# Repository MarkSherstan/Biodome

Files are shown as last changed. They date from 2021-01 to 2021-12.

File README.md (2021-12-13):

# Biodome
Hardware, firmware, and Bluetooth Low Energy (BLE) iOS app for monitoring plants around the house. Inspired by the Cloud Forest in Singapore.

<p align="center">
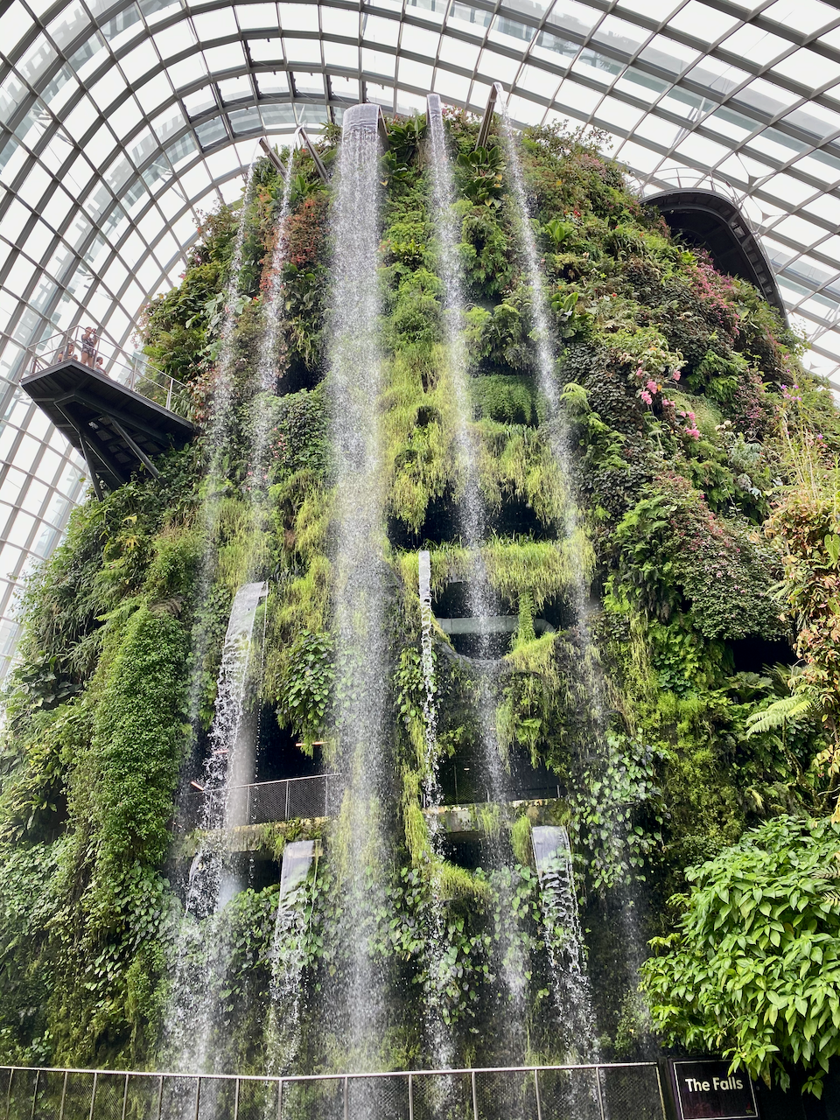
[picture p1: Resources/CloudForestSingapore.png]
  
</p>

# Requirements
## App
* Computer running macOS
* Xcode 13.0 or greater
* Device running iOS 15.0 or greater (UI built for iPhone Xs)

## Hardware
* Raspberry Pi 3B+
* Custom PCB board (boards are built with KiCad 5 and manufactured by JLCPCB))

## Firmware
* Python 3 
* Standard Raspbian OS

# Setup
## App
* Build using Xcode and upload to iOS device. See `/Resources` for example screenshots of the app using simulated data.

## Hardware
* Power on system (remember RPi is 3V3 logic)

## Firmware
As of BlueZ version 5.43 (currently shipped with Raspbian), some BLE aspects are still experimental. You will need to add the 'Experimental' flag to the bluetooth daemon. Open the file: `sudo nano /etc/systemd/system/dbus-org.bluez.service` and add the `-E` flag at the end of the `ExecStart` line. It should look like this:
```
ExecStart=/usr/lib/bluetooth/bluetoothd -E
```
To disable auto battery reading and prevent connection issues, edit the same file and add `-P battery` to the end of the `ExecStart` line to disable the Battery feature in bluetooth. Your ExecStart should look something like:
```
ExecStart=/usr/lib/bluetooth/bluetoothd -E -P battery
```
Run `systemctl daemon-reload` and `systemctl restart bluetooth` to apply the changes to the Bluetooth service

Navigate to `\Firmware` and run `python3 main.py`. The RPi is now ready to share values with the iOS app.

# Future Work
## App
* Fix connection logic
* Connect to multiple devices
* More general UI layout

### Resources 
Core Bluetooth
* https://www.raywenderlich.com/231-core-bluetooth-tutorial-for-ios-heart-rate-monitor#toc-anchor-009
* https://www.novelbits.io/intro-ble-mobile-development-ios-part-2/
* https://learn.adafruit.com/build-a-bluetooth-app-using-swift-5/code
* https://punchthrough.com/core-bluetooth-basics/

Style and UI:
*  https://betterprogramming.pub/flat-design-list-swiftui-part-i-ab9e841720cd
*  https://developer.apple.com/tutorials/swiftui/building-lists-and-navigation
*  https://betterprogramming.pub/creating-an-apple-like-splash-screen-in-swiftui-fdeb36b47e81

Other:
* https://www.raywenderlich.com/2164-arduino-tutorial-integrating-bluetooth-le-and-ios-with-swift#toc-anchor-009

## Hardware
* Use digital pin to wake up moisture sensor (change to 3.3V 555 timer)
* Check backorder on BME280 - Not currently used for V1
* Make the board act as a shield for the Pi (pins and mounting holes)

## Firmware 
* Website JavaScript interface (similar to Octo-Print)
* Slow logging... Log on ram for 24h then save to SD card (Dont burn out SD card)
* Photos/Image Processing, moisture, humidity, temperature, light, pressure

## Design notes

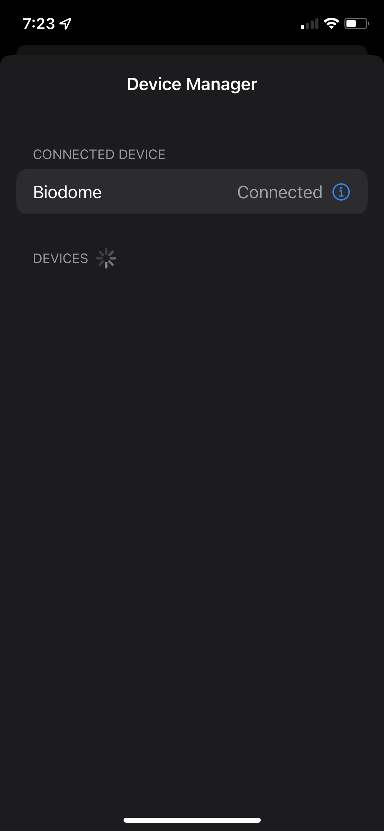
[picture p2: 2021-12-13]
Resources/AppDeviceManager.PNG

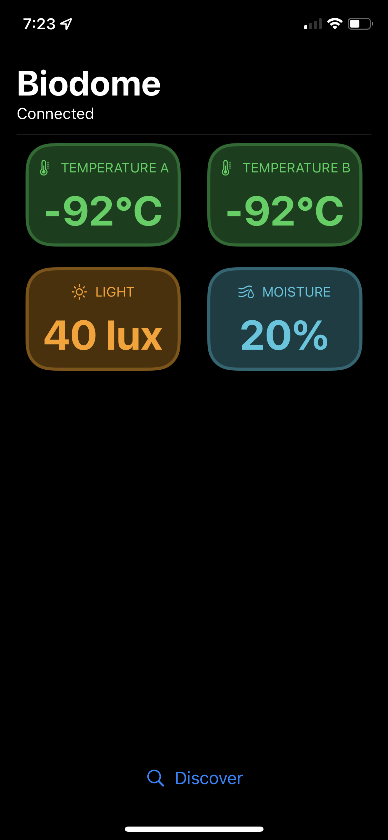
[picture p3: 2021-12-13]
Resources/AppMainView.PNG

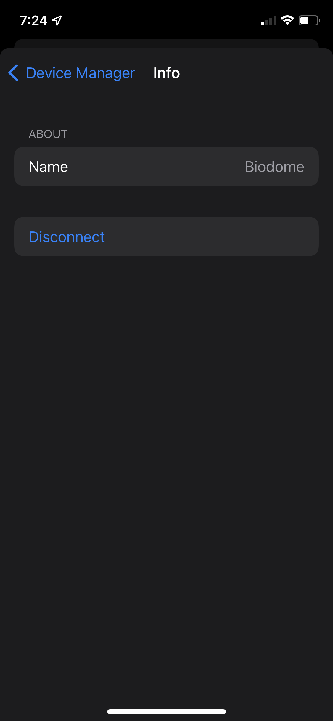
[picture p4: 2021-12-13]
Resources/AppInfoView.PNG

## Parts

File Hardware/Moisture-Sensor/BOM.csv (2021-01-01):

Reference | Quantity | Value | Footprint | Digi-Key # | Digi-Key Link | Manufacturer | Manufacturer #
C1 | 1 | 470 pF | Capacitor_SMD:C_0603_1608Metric_Pad1.05x0.95mm_HandSolder
C2 C3 | 2 | 0.1 uF | Capacitor_SMD:C_0603_1608Metric_Pad1.05x0.95mm_HandSolder
C4 | 1 | 10 nF | Capacitor_SMD:C_0603_1608Metric_Pad1.05x0.95mm_HandSolder
C5 | 1 | 4.7 uF | Capacitor_SMD:C_0603_1608Metric_Pad1.05x0.95mm_HandSolder
D1 | 1 | Green 2.2V 20mA | LED_SMD:LED_0603_1608Metric_Pad1.05x0.95mm_HandSolder
D2 | 1 | 4148 | Diode_SMD:D_SOD-123 | SMMSD4148T3GOSCT-ND | https://www.digikey.ca/en/products/detail/on-semiconductor/SMMSD4148T3G/3062785 | ON Semiconductor | SMMSD4148T3G
H1 H2 | 2 | M2 | MountingHole:MountingHole_2.2mm_M2_ISO14580_Pad
J1 | 1 | Input | Connector_PinHeader_2.54mm:PinHeader_1x03_P2.54mm_Vertical
R1 | 1 | 150 ohm | Resistor_SMD:R_0603_1608Metric_Pad1.05x0.95mm_HandSolder
R2 | 1 | DNP | Resistor_SMD:R_0603_1608Metric_Pad1.05x0.95mm_HandSolder
R3 | 1 | 0 ohm | Resistor_SMD:R_0603_1608Metric_Pad1.05x0.95mm_HandSolder
R4 | 1 | 1.5 kohm | Resistor_SMD:R_0603_1608Metric_Pad1.05x0.95mm_HandSolder
R5 | 1 | 2.4 kohm | Resistor_SMD:R_0603_1608Metric_Pad1.05x0.95mm_HandSolder
R6 | 1 | 100 ohm | Resistor_SMD:R_0603_1608Metric_Pad1.05x0.95mm_HandSolder
R7 | 1 | 10 kohm | Resistor_SMD:R_0603_1608Metric_Pad1.05x0.95mm_HandSolder
R8 | 1 | 1 Mohm | Resistor_SMD:R_0603_1608Metric_Pad1.05x0.95mm_HandSolder
U1 | 1 | LMV358 | Package_SO:SOIC-8_3.9x4.9mm_P1.27mm | 296-39049-5-ND | https://www.digikey.ca/en/products/detail/texas-instruments/LMV358ID/1510583 | Texas Instruments | LMV358ID
U2 | 1 | NE555 | Package_SO:SOIC-8_3.9x4.9mm_P1.27mm | 296-6501-1-ND | https://www.digikey.ca/en/products/detail/texas-instruments/NE555DR/372491 | Texas Instruments | NE555DR

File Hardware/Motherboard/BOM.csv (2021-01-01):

Reference | Quantity | Value | Footprint | Digi-Key # | Digi-Key Link | Manufacturer | Manufacturer #
C1 C5 | 2 | 1 uF | Capacitor_SMD:C_0603_1608Metric_Pad1.05x0.95mm_HandSolder
C3 C2 C4 | 3 | 0.1 uF | Capacitor_SMD:C_0603_1608Metric_Pad1.05x0.95mm_HandSolder
D1 | 1 | Blue 3.3V 20mA | LED_SMD:LED_0603_1608Metric_Pad1.05x0.95mm_HandSolder
D2 | 1 | Green 2.2V 20mA | LED_SMD:LED_0603_1608Metric_Pad1.05x0.95mm_HandSolder
H1 H2 H3 H4 | 4 | M3 | MountingHole:MountingHole_3.2mm_M3_ISO7380_Pad
J1 | 1 | AUX Analog A | Connector_PinHeader_2.54mm:PinHeader_1x03_P2.54mm_Vertical
J10 | 1 | Moisture 4 | Connector_PinHeader_2.54mm:PinHeader_1x03_P2.54mm_Vertical
J11 | 1 | Moisture 5 | Connector_PinHeader_2.54mm:PinHeader_1x03_P2.54mm_Vertical
J12 | 1 | Power In | Connector_BarrelJack:BarrelJack_CUI_PJ-102AH_Horizontal | CP-102AH-ND | https://www.digikey.ca/en/products/detail/cui-devices/PJ-102AH/408448?s=N4IgTCBcDaIAoCkC0BGADGAggCRAXQF8g | CUI Devices | PJ-102AH
J2 | 1 | AUX Analog B | Connector_PinHeader_2.54mm:PinHeader_1x03_P2.54mm_Vertical
J3 | 1 | RPi 3B+ | Connector_PinHeader_2.54mm:PinHeader_2x20_P2.54mm_Vertical
J4 | 1 | AUX Digital A | Connector_PinHeader_2.54mm:PinHeader_1x03_P2.54mm_Vertical
J5 | 1 | AUX Digital B | Connector_PinHeader_2.54mm:PinHeader_1x03_P2.54mm_Vertical
J6 | 1 | Moisture 0 | Connector_PinHeader_2.54mm:PinHeader_1x03_P2.54mm_Vertical
J7 | 1 | Moisture 1 | Connector_PinHeader_2.54mm:PinHeader_1x03_P2.54mm_Vertical
J8 | 1 | Moisture 2 | Connector_PinHeader_2.54mm:PinHeader_1x03_P2.54mm_Vertical
J9 | 1 | Moisture 3 | Connector_PinHeader_2.54mm:PinHeader_1x03_P2.54mm_Vertical
R18 | 1 | 150 ohm | Resistor_SMD:R_0603_1608Metric_Pad1.05x0.95mm_HandSolder
R2 R4 R8 R10 R12 R14 | 6 | 1.7 kohm | Resistor_SMD:R_0603_1608Metric_Pad1.05x0.95mm_HandSolder
R3 R5 R9 R11 R13 R15 | 6 | 3.3 kohm | Resistor_SMD:R_0603_1608Metric_Pad1.05x0.95mm_HandSolder
R6 R7 R16 R17 | 4 | 4.7 kohm | Resistor_SMD:R_0603_1608Metric_Pad1.05x0.95mm_HandSolder
U1 | 1 | MCP3008 | Package_SO:SOIC-16_3.9x9.9mm_P1.27mm | MCP3008T-I/SLCT-ND | https://www.digikey.ca/en/products/detail/microchip-technology/MCP3008T-I-SL/319424 | Microchip Technology | MCP3008T-I/SL
U2 | 1 | BME280 | Package_LGA:Bosch_LGA-8_2.5x2.5mm_P0.65mm_ClockwisePinNumbering | 828-1063-1-ND | https://www.digikey.ca/en/products/detail/bosch-sensortec/BME280/6136306 | Bosch Sensortec | BME280
U3 | 1 | VEML7700 | Custom:VEML7700 | VEML7700CT-ND | https://www.digikey.ca/en/products/detail/vishay-semiconductor-opto-division/VEML7700-TR/5820243 | Vishay Semiconductor Opto Division | VEML7700-TR

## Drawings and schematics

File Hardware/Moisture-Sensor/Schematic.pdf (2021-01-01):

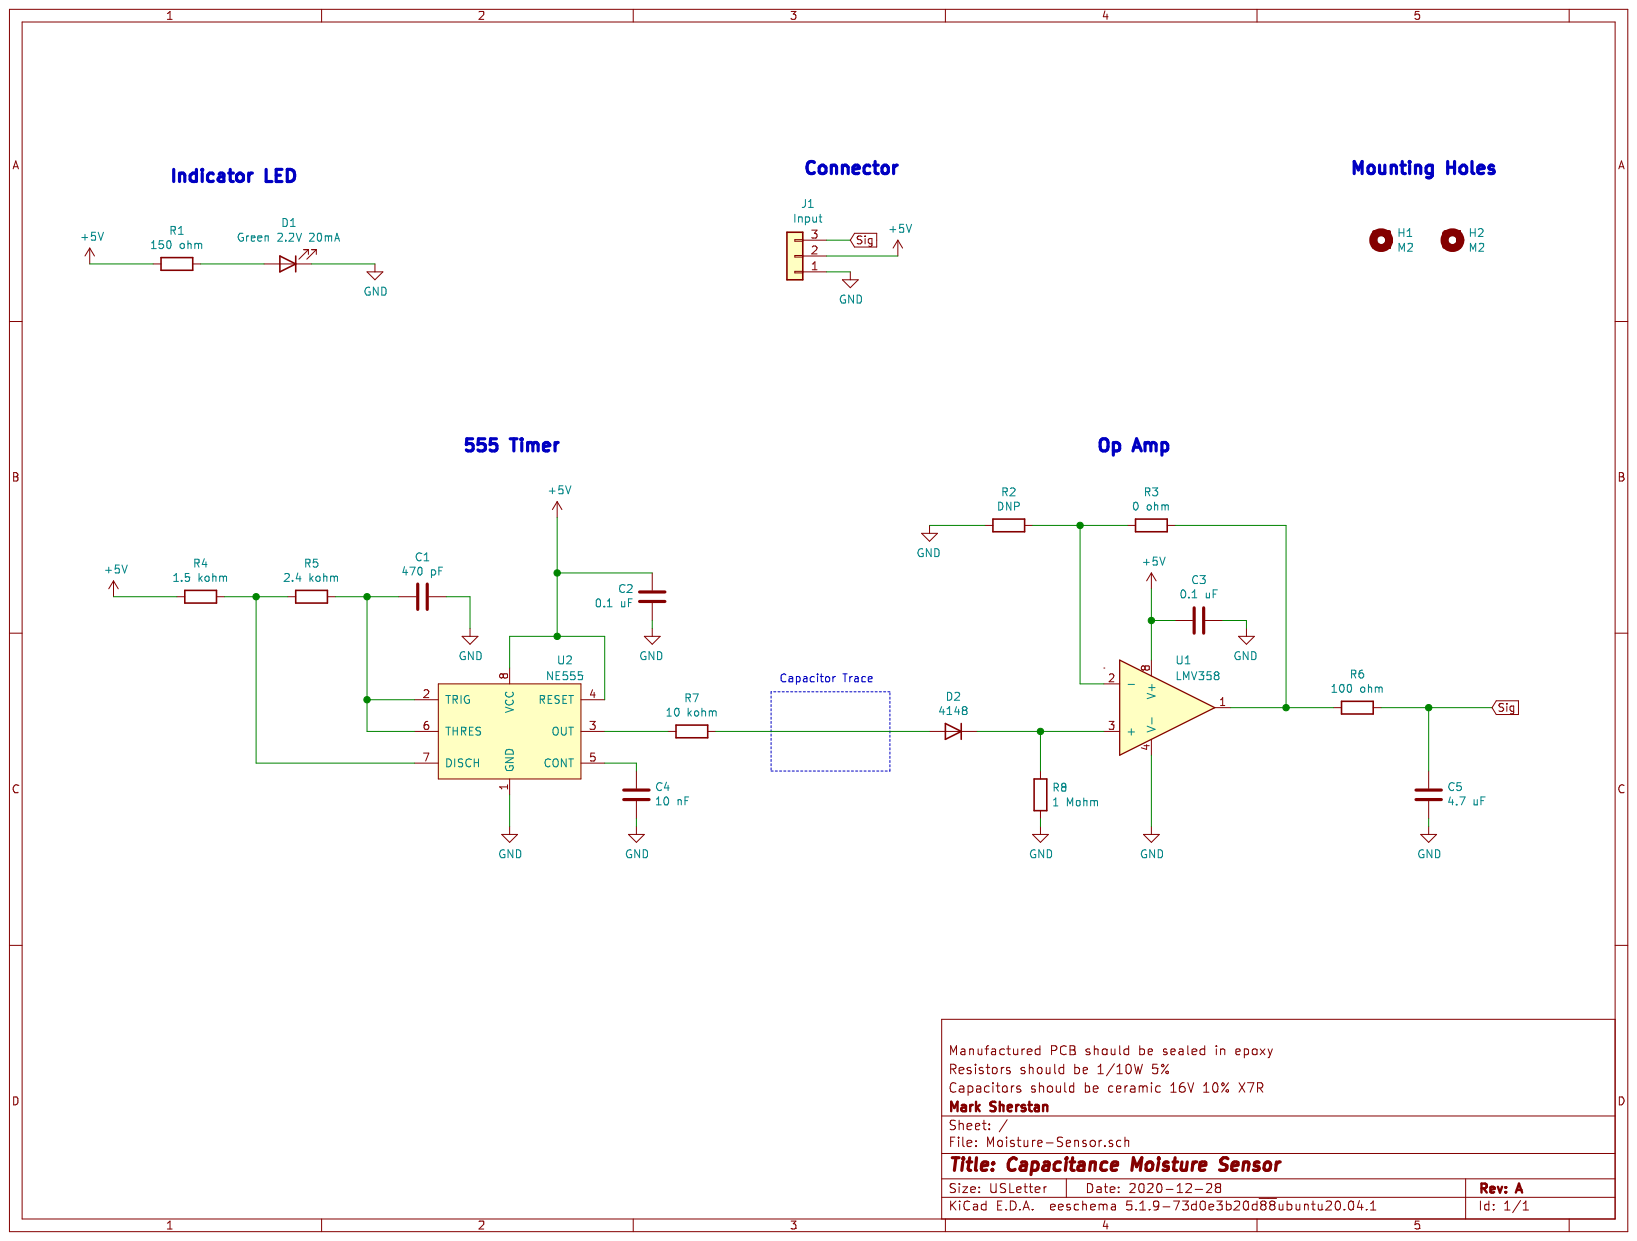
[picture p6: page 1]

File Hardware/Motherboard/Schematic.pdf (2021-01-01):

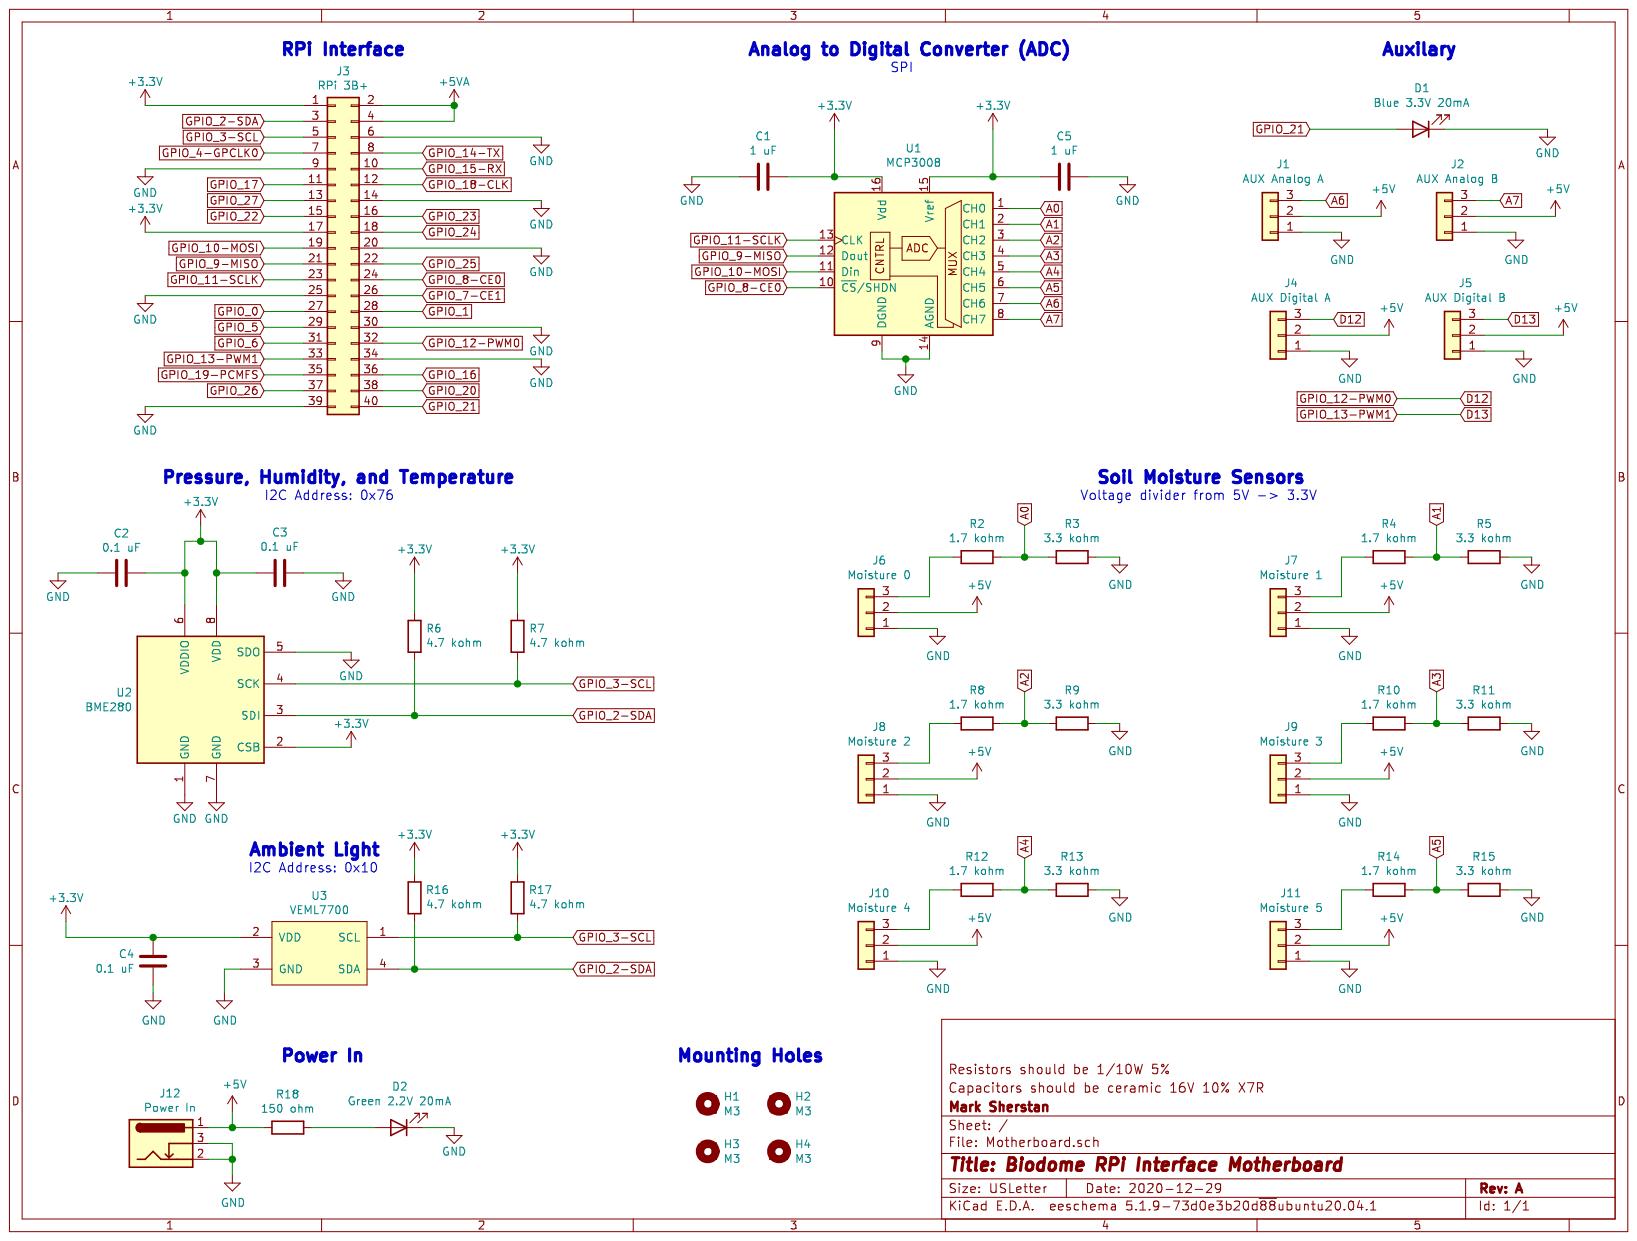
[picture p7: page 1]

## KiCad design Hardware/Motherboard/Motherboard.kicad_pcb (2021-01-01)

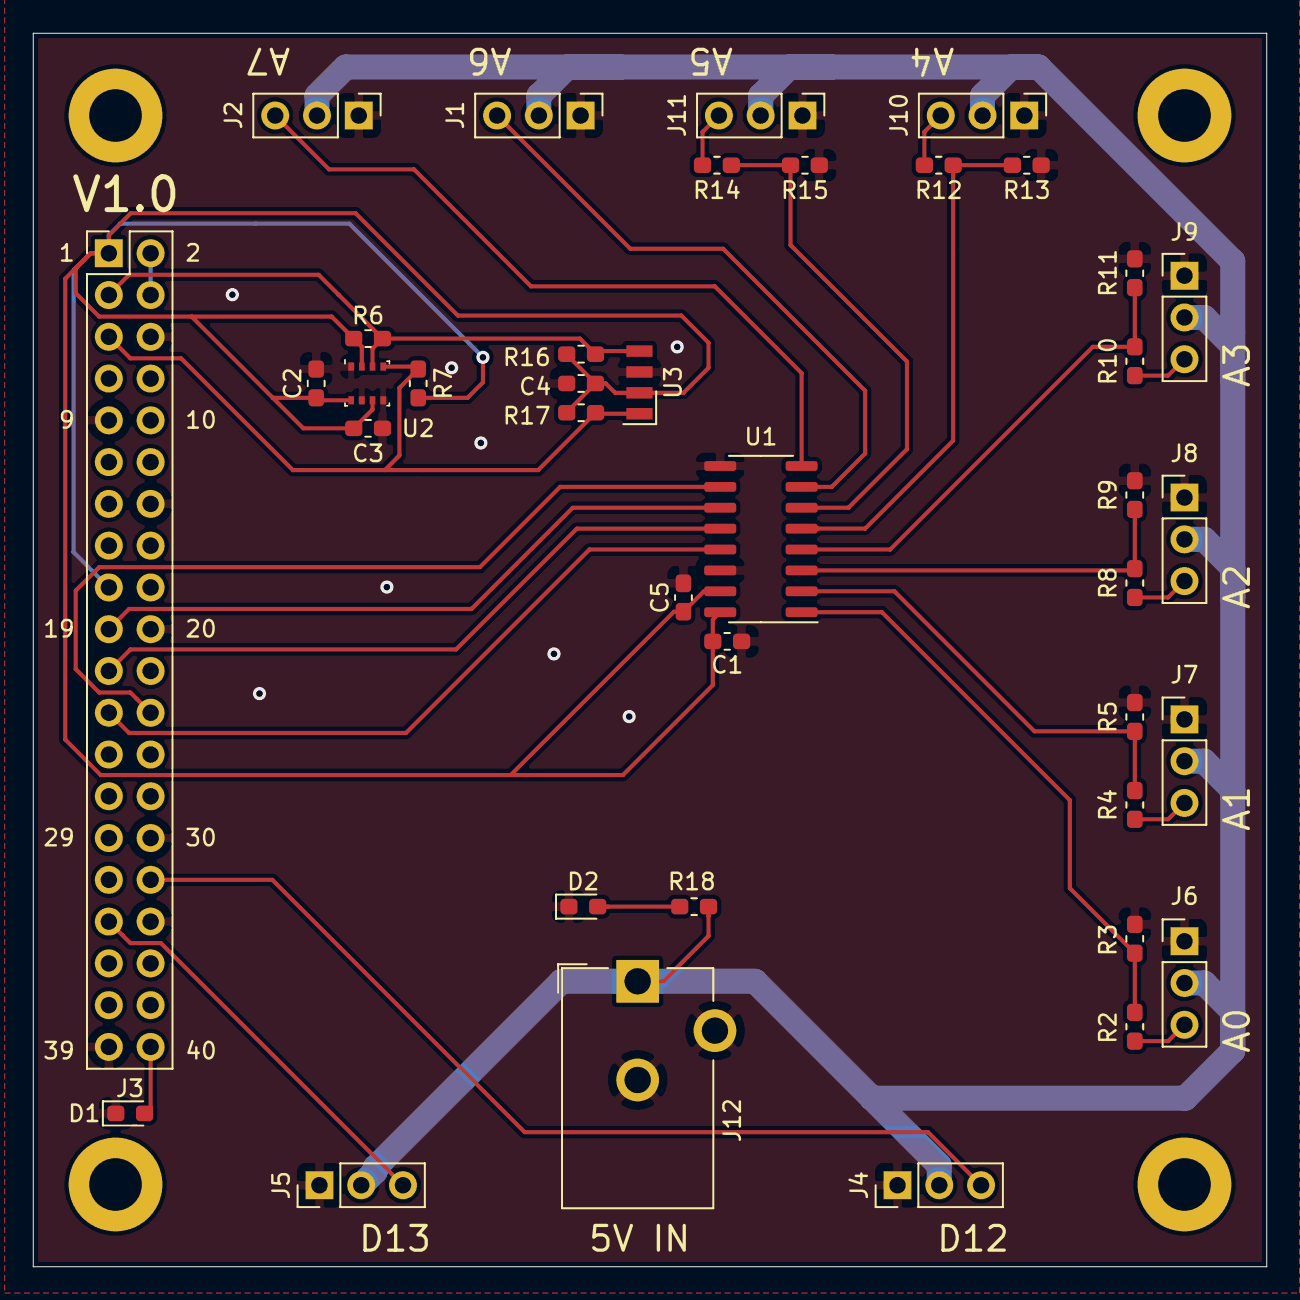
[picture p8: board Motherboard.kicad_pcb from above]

Board: 2 copper layers, 75.0 x 75.0 mm, 43 parts (0 on the bottom side), 28 nets.

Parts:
C1: 1 uF; C_0603_1608Metric_Pad1.05x0.95mm_HandSolder
C2, C3, C4: 0.1 uF; C_0603_1608Metric_Pad1.05x0.95mm_HandSolder
C5: 1 uF; C_0603_1608Metric_Pad1.08x0.95mm_HandSolder
D1: Blue 3.3V 20mA; LED_0603_1608Metric_Pad1.05x0.95mm_HandSolder
D2: Green 2.2V 20mA; LED_0603_1608Metric_Pad1.05x0.95mm_HandSolder
H1, H2, H3, H4: M3; MountingHole_3.2mm_M3_ISO7380_Pad
J1: AUX Analog A; PinHeader_1x03_P2.54mm_Vertical
J2: AUX Analog B; PinHeader_1x03_P2.54mm_Vertical
J3: RPi 3B+; PinHeader_2x20_P2.54mm_Vertical
J4: AUX Digital A; PinHeader_1x03_P2.54mm_Vertical
J5: AUX Digital B; PinHeader_1x03_P2.54mm_Vertical
J6: Moisture 0; PinHeader_1x03_P2.54mm_Vertical
J7: Moisture 1; PinHeader_1x03_P2.54mm_Vertical
J8: Moisture 2; PinHeader_1x03_P2.54mm_Vertical
J9: Moisture 3; PinHeader_1x03_P2.54mm_Vertical
J10: Moisture 4; PinHeader_1x03_P2.54mm_Vertical
J11: Moisture 5; PinHeader_1x03_P2.54mm_Vertical
J12: Power In; BarrelJack_CUI_PJ-102AH_Horizontal
R2, R4, R8, R10, R12, R14: 1.7 kohm; R_0603_1608Metric_Pad1.05x0.95mm_HandSolder
R3, R5, R9, R11, R13, R15: 3.3 kohm; R_0603_1608Metric_Pad1.05x0.95mm_HandSolder
R6, R7, R16, R17: 4.7 kohm; R_0603_1608Metric_Pad1.05x0.95mm_HandSolder
R18: 150 ohm; R_0603_1608Metric_Pad1.05x0.95mm_HandSolder
U1: MCP3008; SOIC-16_3.9x9.9mm_P1.27mm
U2: BME280; Bosch_LGA-8_2.5x2.5mm_P0.65mm_ClockwisePinNumbering
U3: VEML7700

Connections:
+3V3: C1.2, C2.1, C3.1, C4.1, C5.1, J3.1, J3.17, R6.2, R7.2, R16.2, R17.2, U1.15, U1.16, U2.2, U2.6, U2.8, U3.2
+5V: J1.2, J2.2, J4.2, J5.2, J6.2, J7.2, J8.2, J9.2, J10.2, J11.2, J12.1, R18.1
+5VA: J3.2, J3.4
A0: R2.2, R3.1, U1.1
A1: R4.2, R5.1, U1.2
A2: R8.2, R9.1, U1.3
A3: R10.2, R11.1, U1.4
A4: R12.2, R13.1, U1.5
A5: R14.2, R15.1, U1.6
A6: J1.3, U1.7
A7: J2.3, U1.8
D12: J3.32, J4.3
D13: J3.33, J5.3
GND: C1.1, C2.2, C3.2, C4.2, C5.2, D1.1, D2.1, J1.1, J2.1, J3.6, J3.9, J3.14, J3.20, J3.25, J3.30, J3.34, J3.39, J4.1, J5.1, J6.1, J7.1, J8.1, J9.1, J10.1, J11.1, J12.2, J12.3, R3.2, R5.2, R9.2, R11.2, R13.2, R15.2, U1.9, U1.14, U2.1, U2.5, U2.7, U3.3
GPIO_2-SDA: J3.3, R6.1, R16.1, U2.3, U3.4
GPIO_3-SCL: J3.5, R7.1, R17.1, U2.4, U3.1
GPIO_8-CE0: J3.24, U1.10
GPIO_9-MISO: J3.21, U1.12
GPIO_10-MOSI: J3.19, U1.11
GPIO_11-SCLK: J3.23, U1.13
GPIO_21: D1.2, J3.40
unnamed: D2.2, R18.2
unnamed: J6.3, R2.1
unnamed: J7.3, R4.1
unnamed: J8.3, R8.1
unnamed: J9.3, R10.1
unnamed: J10.3, R12.1
unnamed: J11.3, R14.1

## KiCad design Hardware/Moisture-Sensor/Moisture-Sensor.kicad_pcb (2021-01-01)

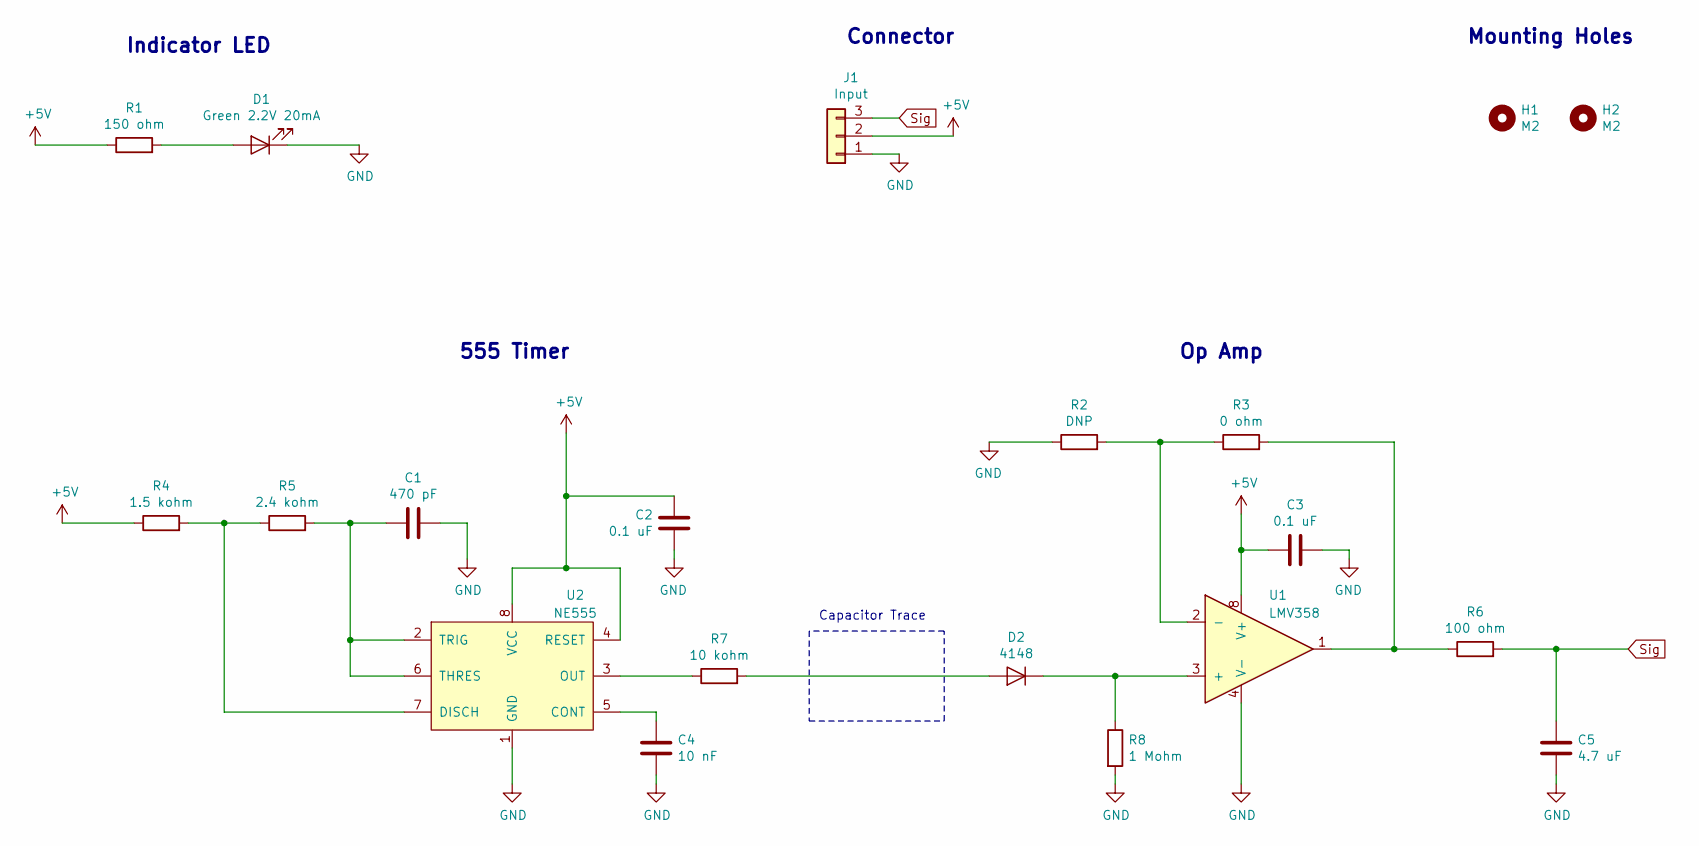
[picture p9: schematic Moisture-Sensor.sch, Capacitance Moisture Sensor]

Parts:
C1: 470 pF; C_0603_1608Metric_Pad1.05x0.95mm_HandSolder
C2, C3: 0.1 uF; C_0603_1608Metric_Pad1.05x0.95mm_HandSolder
C4: 10 nF; C_0603_1608Metric_Pad1.05x0.95mm_HandSolder
C5: 4.7 uF; C_0603_1608Metric_Pad1.05x0.95mm_HandSolder
D1: Green 2.2V 20mA; LED_0603_1608Metric_Pad1.05x0.95mm_HandSolder
D2: 4148; D_SOD-123; Manufacturer # SMMSD4148T3G; Digi-Key # SMMSD4148T3GOSCT-ND
H1, H2: M2; MountingHole_2.2mm_M2_ISO14580_Pad
J1: Input; PinHeader_1x03_P2.54mm_Vertical
R1: 150 ohm; R_0603_1608Metric_Pad1.05x0.95mm_HandSolder
R2: DNP; R_0603_1608Metric_Pad1.05x0.95mm_HandSolder
R3: 0 ohm; R_0603_1608Metric_Pad1.05x0.95mm_HandSolder
R4: 1.5 kohm; R_0603_1608Metric_Pad1.05x0.95mm_HandSolder
R5: 2.4 kohm; R_0603_1608Metric_Pad1.05x0.95mm_HandSolder
R6: 100 ohm; R_0603_1608Metric_Pad1.05x0.95mm_HandSolder
R7: 10 kohm; R_0603_1608Metric_Pad1.05x0.95mm_HandSolder
R8: 1 Mohm; R_0603_1608Metric_Pad1.05x0.95mm_HandSolder
U1: LMV358; SOIC-8_3.9x4.9mm_P1.27mm; Manufacturer # LMV358ID; Digi-Key # 296-39049-5-ND
U2: NE555; SOIC-8_3.9x4.9mm_P1.27mm; Manufacturer # NE555DR; Digi-Key # 296-6501-1-ND

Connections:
+5V: C2.2, C3.2, J1.2, R1.1, R4.1, U1.8 (V+), U2.4 (RESET), U2.8 (VCC)
GND: C1.1, C2.1, C3.1, C4.1, C5.1, D1.1 (K), J1.1, R2.1, R8.2, U1.4 (V-), U2.1 (GND)
unnamed: C1.2, R5.2, U2.2 (TRIG), U2.6 (THRES)
unnamed: C4.2, U2.5 (CONT)
unnamed: D1.2 (A), R1.2
unnamed: D2.1 (K), R8.1, U1.3 (+)
unnamed: D2.2 (A), R7.2
unnamed: R2.2, R3.1, U1.2 (-)
unnamed: R3.2, R6.1, U1.1
unnamed: R4.2, R5.1, U2.7 (DISCH)
unnamed: R7.1, U2.3 (OUT)
Sig: C5.2, J1.3, R6.2

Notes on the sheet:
Indicator LED
Connector
555 Timer
Op Amp
Capacitor Trace
Mounting Holes

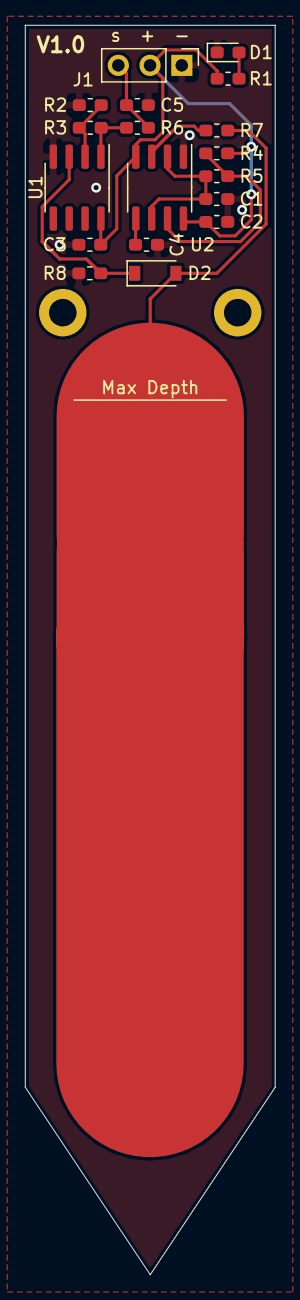
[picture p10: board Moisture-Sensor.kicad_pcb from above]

Board: 2 copper layers, 20.0 x 100.0 mm, 20 parts (0 on the bottom side), 12 nets.

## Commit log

2020-12-27 Selected MCP3008 for ADC and started RPi pinout
    [Motherboard.sch]
2020-12-27 Selected most of the required components
    [Moisture-Sensor.sch]
2020-12-28 Labeled RPi GPIO pin and MCP3008. Need 5v external
    [Motherboard.sch]
2020-12-28 555 timer complete
    [Moisture-Sensor.sch]
2020-12-28 Op amp is updated
    [Moisture-Sensor.sch]
2020-12-28 Schematic just needs a double check
    [Moisture-Sensor.sch]
2020-12-28 started layout
    [Moisture-Sensor.kicad_pcb]
2020-12-28 Need to find an ambient light sensor
    [Motherboard.sch]
2020-12-28 Schematic reviewed
    [Moisture-Sensor.sch]
2020-12-28 half layed out, switch to other computer
    [Moisture-Sensor.kicad_pcb]
2020-12-28 Almost done routing, need to move bypass caps
    [Moisture-Sensor.kicad_pcb, Moisture-Sensor.sch]
2020-12-28 Layout looks good and passed DRC
    [Moisture-Sensor.kicad_pcb]
2020-12-28 Create gerbers
    [Moisture-Sensor-B_Cu.gbr, Moisture-Sensor-B_Mask.gbr, Moisture-Sensor-B_Paste.gbr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]
2020-12-28 schematic looks mostly routed, need to finalize components
    [Motherboard.sch]
2020-12-29 Schematic mostly done, just need to double check
    [Motherboard.sch]
2020-12-29 Quick layout before schematic review
    [Motherboard.kicad_pcb, Motherboard.sch]
2020-12-30 Schematic is fully reviewed
    [Motherboard.sch]
2020-12-30 added missing footprint on new cap
    [Motherboard.kicad_pcb, Motherboard.sch]
2020-12-30 Analog routed
    [Motherboard.kicad_pcb]
2020-12-30 Routing complete
    [Motherboard.kicad_pcb]
2020-12-30 generate gerbers
    [Motherboard-B_Cu.gbr, Motherboard-B_Mask.gbr, Motherboard-B_Paste.gbr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]
2020-12-30 add silk screen
    [Motherboard-B_Cu.gbr, Motherboard-B_Mask.gbr, Motherboard-B_Paste.gbr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]
2020-12-30 Add gerbers
    [Motherboard-B_Cu.gbr, Motherboard-B_Mask.gbr, Motherboard-B_Paste.gbr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]
2020-12-30 Add PDF schematics
2021-01-01 Re commit gerbers
    [Motherboard-B_Cu.gbr, Motherboard-B_Mask.gbr, Motherboard-B_Paste.gbr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]
2021-01-01 Add BOM
    [BOM.csv]
2021-09-11 Increase symbol size and add sensor fields.
2021-09-12 Create BLEManager class and link too a landing scanning page
2021-09-12 Link bluetooth scan view with sensor output view
2021-09-12 Add connection buttons and rough link to BLEclass
2021-09-12 Slotting in pre baked heart rate code (https://www.raywenderlich.com/231-core-bluetooth-tutorial-for-ios-heart-rate-monitor#toc-anchor-009)
2021-09-15 Space out and clean up the UI, make the sensor entry a nice usable class
2021-09-19 Prep for toggle switch and change list to be more general with a struct view and header.
2021-09-22 Add toggle switch for scanning in place of 2x push buttons. Scan for all devices and filter by name incase UUID is not advertised.
2021-09-23 Create hardware directory
    [BOM.csv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]
2021-10-02 Remove onHeartRateReceived, discover all services, and bit shift temperature readings.
2021-10-03 Switch from List to Grid
2021-10-06 Add interaction where connected device is separated list -> Need to add connection logic still.
2021-10-06 Have progress view when selecting a device.
2021-10-06 Remove progress wheel and just put everything in connection list with status. Commented out log noise of connection messages and characteristics.
2021-10-07 Put dashes when there is no connected device on UI values.
2021-10-09 Add navigation based on button press and start configuring the info view.
2021-10-09 Fix bug where sometimes device name went on 2 lines.
2021-12-08 Fix bit shift data type and delete some print statements
2021-12-09 Add parameter structure to sensor widgets and started commenting code
2021-12-11 Update the two temperature values independently
2021-12-13 Add sensor class for a data stream
2021-12-13 Create moisture and light sensor classes
